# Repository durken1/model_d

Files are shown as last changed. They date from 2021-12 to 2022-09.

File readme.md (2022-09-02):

# Model D

model_d
## Note: I got this working using a fork of QMK for XWhatsit by deskthority user pandrew. There is probably room for improvement in the PCB - the current version is basically a working prototype, so use this at your own peril. No guarantees :)

40% ortho keyboard using a capacitive pcb and Model F switches.

The ground plate is important to avoid interference and is to be placed beneath the main pcb.

## Case
I have included the STLs (cut to be printable on "normal" sized printers, I used an Ender 3 V2) for my case as well as the step file, so it should be easy to make adjustments to fit your need. 
I used M3 inserts and screws for attaching stuff (all the 4mm round holes).

The PCBs slide into the plate that is then attached to the main case using the mounting bracket. The plate is designed with 0.8 mm PCBs in mind (1.6 mm total for main + ground pcb).

I think most of the assembly is pretty straight forward, so I won't make a guide unless there is demand for one. Feel free to contact me with any questions though.

For my build I used a TH-xwhatsit and a short USB C panel mount extension cable.

bracket1
bracket2

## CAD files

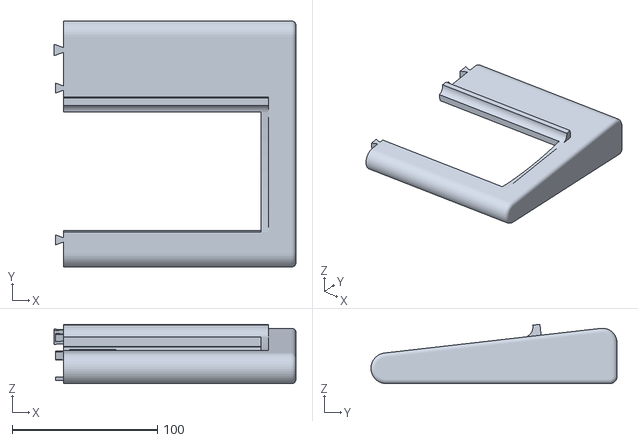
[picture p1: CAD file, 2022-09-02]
case/stl/Case_main_R.stl
166.6 x 169.4 x 40.9

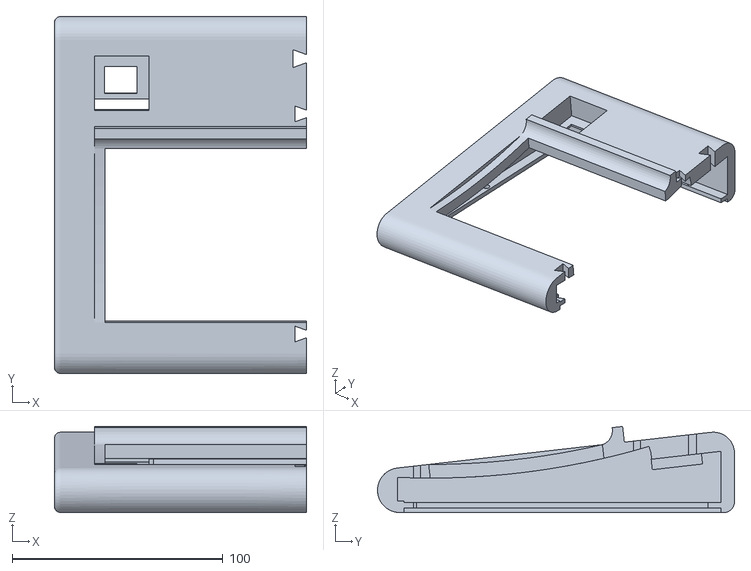
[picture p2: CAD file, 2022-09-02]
case/stl/Case_main_L.stl
119.8 x 169.5 x 40.9

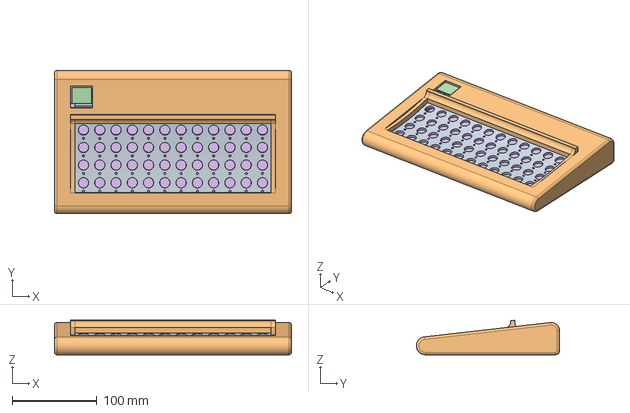
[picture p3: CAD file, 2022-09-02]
case/step/model_d_case_v4.0.step
280.0 x 169.5 x 40.9 mm

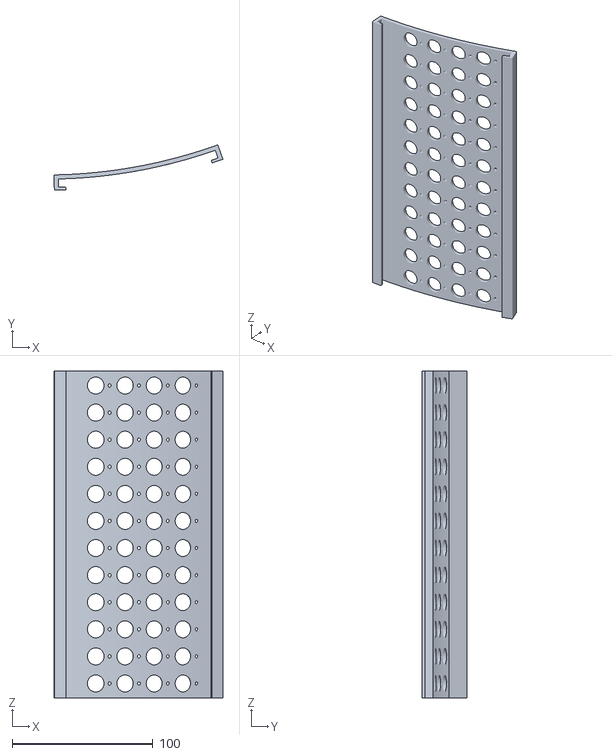
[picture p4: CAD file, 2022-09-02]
case/stl/Plate.stl
119.9 x 32.1 x 232.0

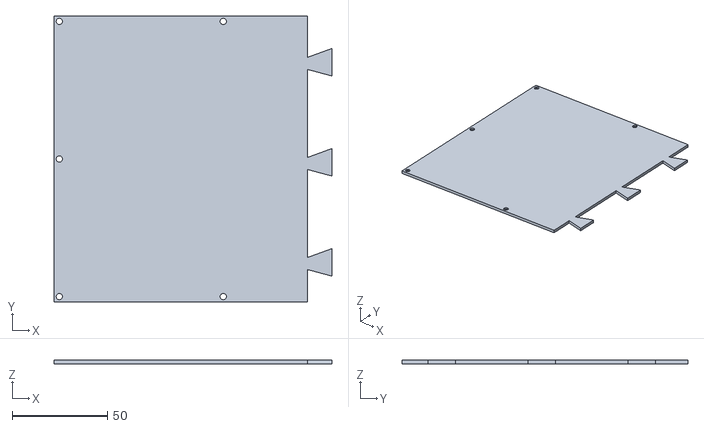
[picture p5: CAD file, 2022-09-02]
case/stl/Bottom_L.stl
145.9 x 150.0 x 2.00

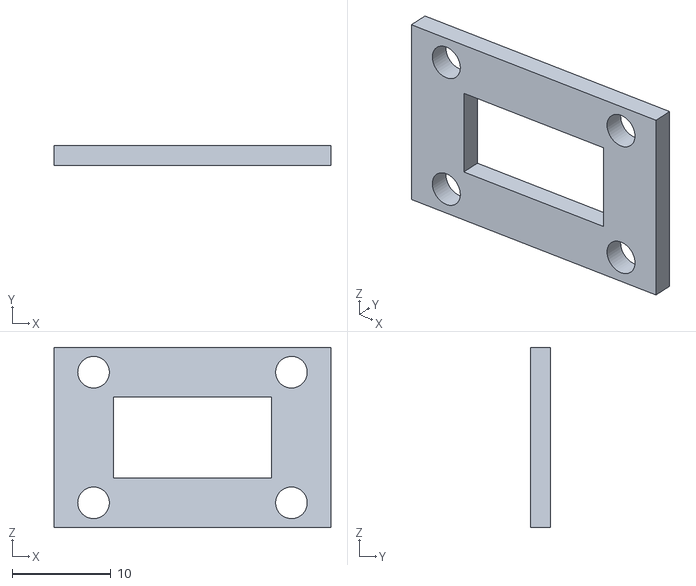
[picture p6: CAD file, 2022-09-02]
case/stl/USB_bracket.stl
28.0 x 2.00 x 18.2

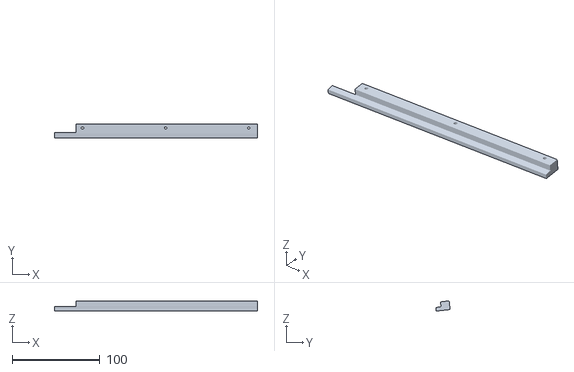
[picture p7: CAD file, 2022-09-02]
case/stl/Bracket.stl
232.0 x 16.4 x 11.7

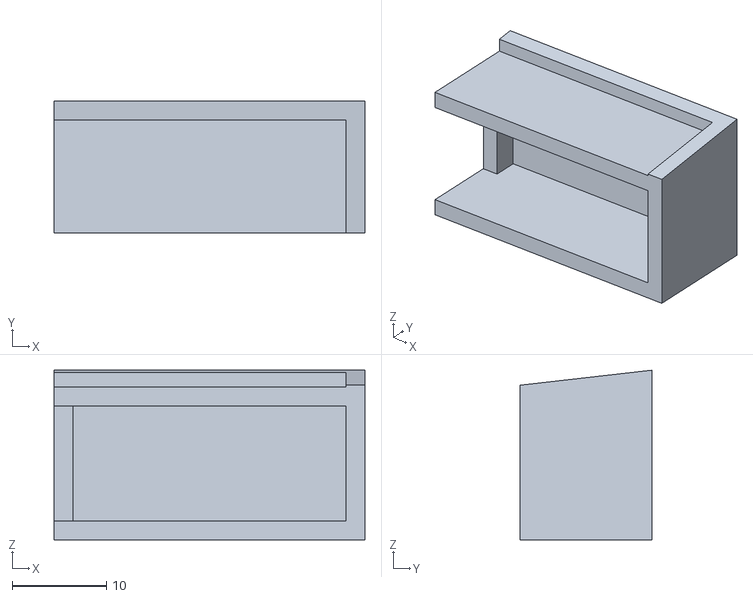
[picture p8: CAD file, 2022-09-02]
case/stl/solenoid.stl
33.0 x 14.0 x 18.0

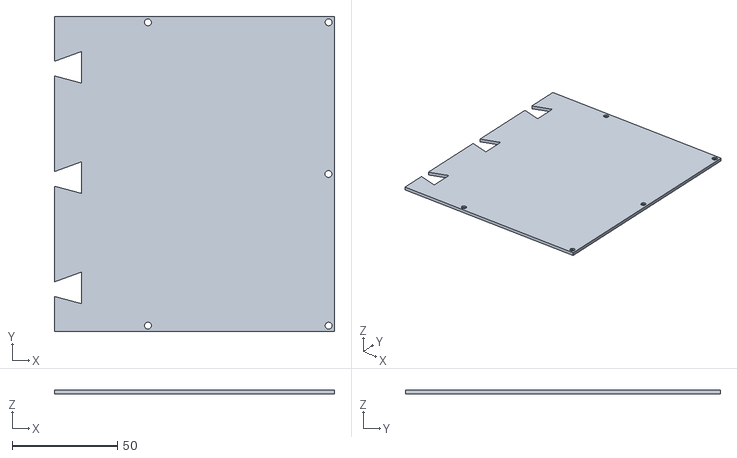
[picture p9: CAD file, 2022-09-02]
case/stl/Bottom_R.stl
133.3 x 150.0 x 2.00

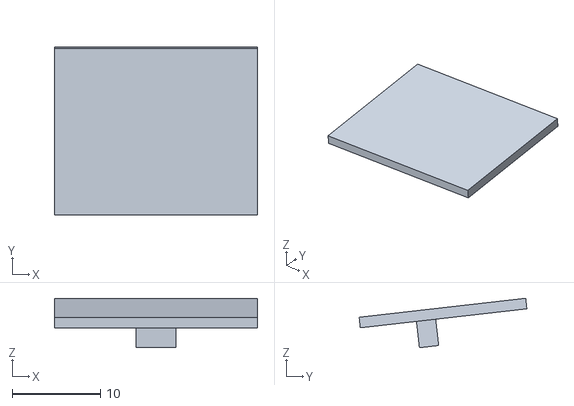
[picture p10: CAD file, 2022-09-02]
case/stl/skcm-keycap.stl
23.0 x 19.0 x 5.60

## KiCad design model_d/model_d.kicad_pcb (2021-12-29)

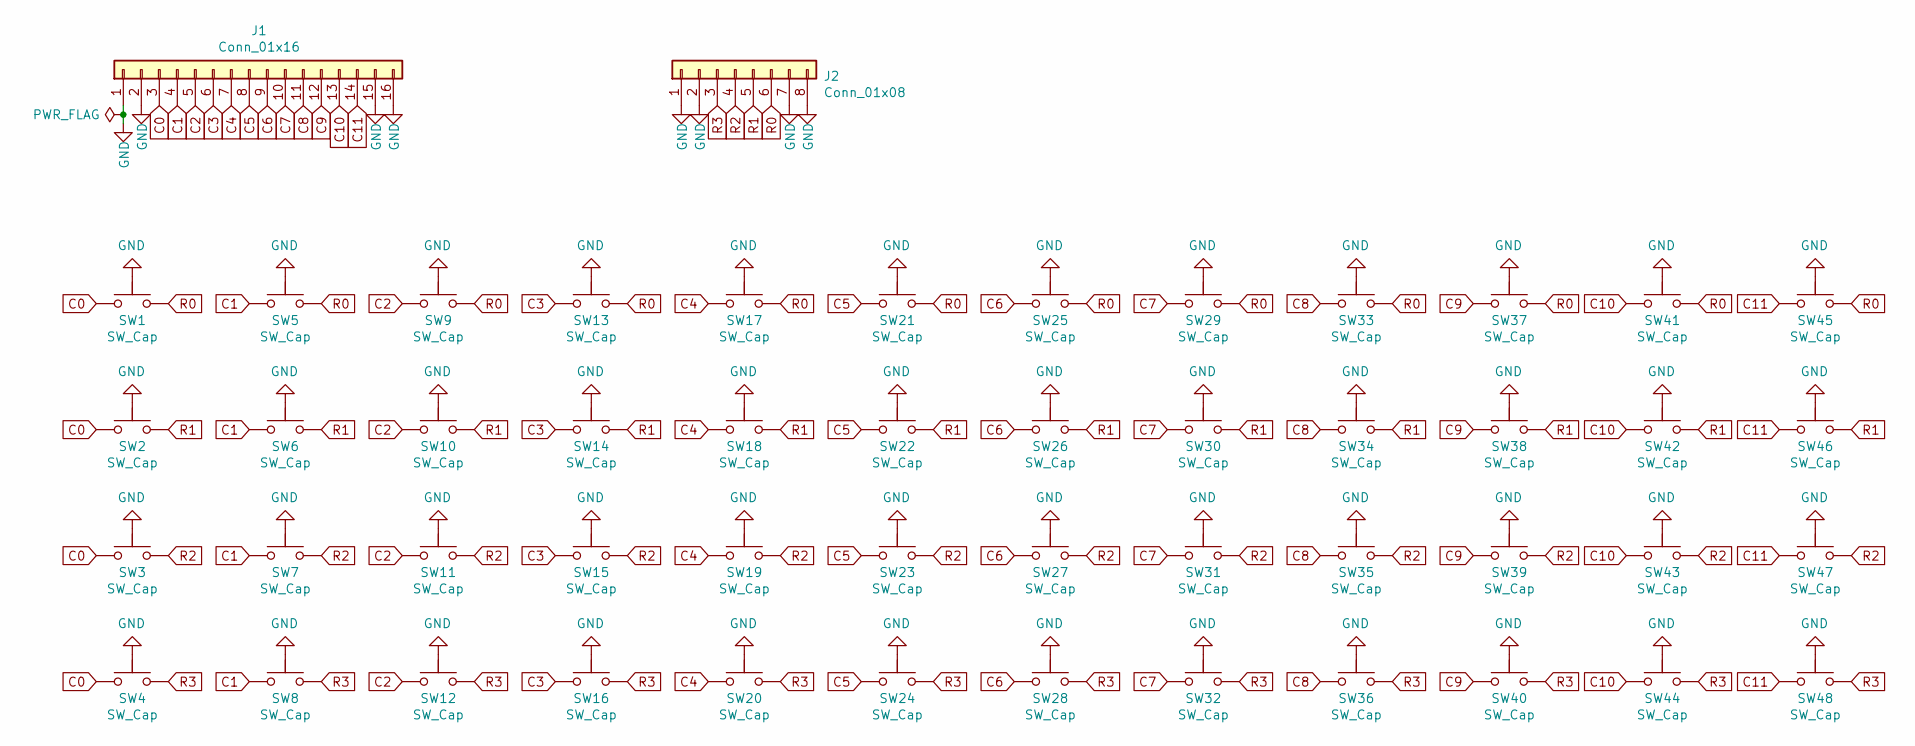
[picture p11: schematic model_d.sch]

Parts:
J1: Conn_01x16; PinHeader_1x16_P2.54mm_Vertical
J2: Conn_01x08; PinHeader_1x08_P2.54mm_Vertical
SW1, SW2, SW3, SW4, SW5, SW6, SW7, SW8, SW9, SW10, SW11, SW12, SW13, SW14, SW15, SW16, SW17, SW18, SW19, SW20, SW21, SW22, SW23, SW24, SW25, SW26, SW27, SW28, SW29, SW30, SW31, SW32, SW33, SW34, SW35, SW36, SW37, SW38, SW39, SW40, SW41, SW42, SW43, SW44, SW45, SW46, SW47, SW48: SW_Cap; capswitch2

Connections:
C0: J1.3, SW1.DRIVE, SW2.DRIVE, SW3.DRIVE, SW4.DRIVE; also elsewhere on the board
C1: J1.4, SW5.DRIVE, SW6.DRIVE, SW7.DRIVE, SW8.DRIVE; also elsewhere on the board
C2: J1.5, SW9.DRIVE, SW10.DRIVE, SW11.DRIVE, SW12.DRIVE; also elsewhere on the board
C3: J1.6, SW13.DRIVE, SW14.DRIVE, SW15.DRIVE, SW16.DRIVE; also elsewhere on the board
C4: J1.7, SW17.DRIVE, SW18.DRIVE, SW19.DRIVE, SW20.DRIVE; also elsewhere on the board
C5: J1.8, SW21.DRIVE, SW22.DRIVE, SW23.DRIVE, SW24.DRIVE; also elsewhere on the board
C6: J1.9, SW25.DRIVE, SW26.DRIVE, SW27.DRIVE, SW28.DRIVE; also elsewhere on the board
C7: J1.10, SW29.DRIVE, SW30.DRIVE, SW31.DRIVE, SW32.DRIVE; also elsewhere on the board
C8: J1.11, SW33.DRIVE, SW34.DRIVE, SW35.DRIVE, SW36.DRIVE; also elsewhere on the board
C9: J1.12, SW37.DRIVE, SW38.DRIVE, SW39.DRIVE, SW40.DRIVE; also elsewhere on the board
C10: J1.13, SW41.DRIVE, SW42.DRIVE, SW43.DRIVE, SW44.DRIVE; also elsewhere on the board
C11: J1.14, SW45.DRIVE, SW46.DRIVE, SW47.DRIVE, SW48.DRIVE; also elsewhere on the board
GND: J1.1, J1.2, J1.15, J1.16, J2.1, J2.2, J2.7, J2.8, SW1.GND, SW2.GND, SW3.GND, SW4.GND, SW5.GND, SW6.GND, SW7.GND, SW8.GND, SW9.GND, SW10.GND, SW11.GND, SW12.GND, SW13.GND, SW14.GND, SW15.GND, SW16.GND, SW17.GND, SW18.GND, SW19.GND, SW20.GND, SW21.GND, SW22.GND, SW23.GND, SW24.GND, SW25.GND, SW26.GND, SW27.GND, SW28.GND, SW29.GND, SW30.GND, SW31.GND, SW32.GND, SW33.GND, SW34.GND, SW35.GND, SW36.GND, SW37.GND, SW38.GND, SW39.GND, SW40.GND, SW41.GND, SW42.GND, SW43.GND, SW44.GND, SW45.GND, SW46.GND, SW47.GND, SW48.GND; also elsewhere on the board
R0: J2.6, SW1.SENSE, SW5.SENSE, SW9.SENSE, SW13.SENSE, SW17.SENSE, SW21.SENSE, SW25.SENSE, SW29.SENSE, SW33.SENSE, SW37.SENSE, SW41.SENSE, SW45.SENSE; also elsewhere on the board
R1: J2.5, SW2.SENSE, SW6.SENSE, SW10.SENSE, SW14.SENSE, SW18.SENSE, SW22.SENSE, SW26.SENSE, SW30.SENSE, SW34.SENSE, SW38.SENSE, SW42.SENSE, SW46.SENSE; also elsewhere on the board
R2: J2.4, SW3.SENSE, SW7.SENSE, SW11.SENSE, SW15.SENSE, SW19.SENSE, SW23.SENSE, SW27.SENSE, SW31.SENSE, SW35.SENSE, SW39.SENSE, SW43.SENSE, SW47.SENSE; also elsewhere on the board
R3: J2.3, SW4.SENSE, SW8.SENSE, SW12.SENSE, SW16.SENSE, SW20.SENSE, SW24.SENSE, SW28.SENSE, SW32.SENSE, SW36.SENSE, SW40.SENSE, SW44.SENSE, SW48.SENSE; also elsewhere on the board

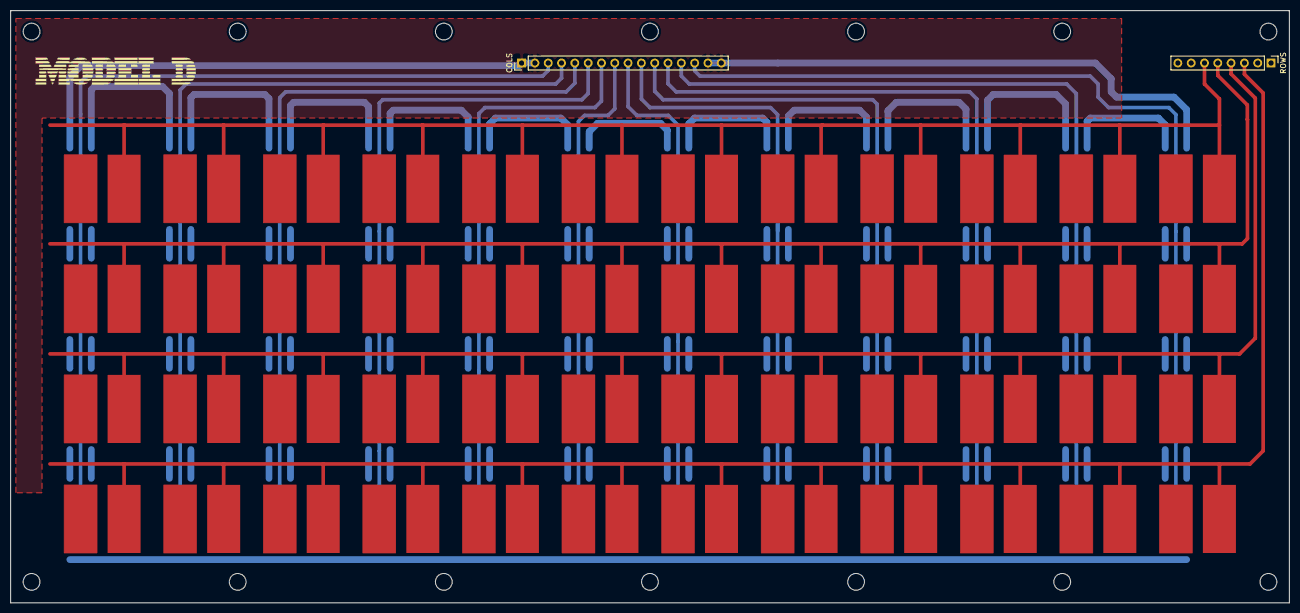
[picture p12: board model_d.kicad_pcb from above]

Board: 2 copper layers, 244.0 x 113.0 mm, 50 parts (0 on the bottom side), 17 nets.

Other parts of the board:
COLS: Conn_01x16; PinHeader_1x16_P2.54mm_Vertical
ROWS: Conn_01x08; PinHeader_1x08_P2.54mm_Vertical

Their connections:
C0: COLS.3; also elsewhere on the board
C1: COLS.4; also elsewhere on the board
C2: COLS.5; also elsewhere on the board
C3: COLS.6; also elsewhere on the board
C4: COLS.7; also elsewhere on the board
C5: COLS.8; also elsewhere on the board
C6: COLS.9; also elsewhere on the board
C7: COLS.10; also elsewhere on the board
C8: COLS.11; also elsewhere on the board
C9: COLS.12; also elsewhere on the board
C10: COLS.13; also elsewhere on the board
C11: COLS.14; also elsewhere on the board
GND: COLS.1, COLS.2, COLS.15, COLS.16, ROWS.1, ROWS.2, ROWS.7, ROWS.8; also elsewhere on the board
R0: ROWS.6; also elsewhere on the board
R1: ROWS.5; also elsewhere on the board
R2: ROWS.4; also elsewhere on the board
R3: ROWS.3; also elsewhere on the board

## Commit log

2021-10-15 init commit
    [model_d.kicad_pcb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]
2021-10-15 footprint done. place and route in progress
    [Gerber_BoardOutline.GKO, Gerber_BottomLayer.GBL, Gerber_BottomSolderMaskLayer.GBS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]
2021-10-19 complete place & route, add gnd plate
    [model_d.kicad_pcb, model_d.sch]
2021-11-15 add STLs, update readme, small cleanup
    [TH-XWhatsIt-B_Cu.gbl, TH-XWhatsIt-B_Mask.gbs, TH-XWhatsIt-B_Paste.gbp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]
2021-12-29 add m3 mounting holes, increase size to 113x244
    [model_d.kicad_pcb, model_d.sch]
2022-01-16 update gerbers
    [model_d-B_Cu.gbl, model_d-B_Mask.gbs, model_d-B_Paste.gbp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]
2022-09-02 add case files
    [Bottom_L.stl, Bottom_R.stl, Bracket.stl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]
2022-09-02 add plate stl
    [Plate.stl]
2022-09-02 remove old proto plate
    [plate_proto_complete.stl, plate_proto_half.stl]
